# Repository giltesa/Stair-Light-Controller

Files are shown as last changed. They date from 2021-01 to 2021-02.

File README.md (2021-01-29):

# Stair Light - Controller [IN PROGRESS]

This project contain 3 boards for making a LED light controller for using with stairs, corridors, or anything where people can cross, and you want to control light effects automatically.

Boards:

1. Stair Light - Controller
2. Stair Light - Controller MicroSD/USB-C
3. Stair Light - Controller PSU

These boards are made for install them inside a BHT-100GA thermostat. I think It can be difficult to find it now, because I bought it 5 years ago for making a WiFi thermostat but finally I discarded my initially idea.

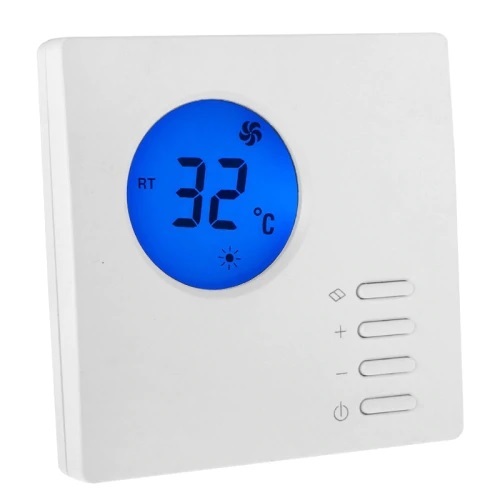
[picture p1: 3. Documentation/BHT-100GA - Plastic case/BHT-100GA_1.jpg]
BHT-100GA


Anyway, you can use the circuit in your own case if you want.

The circuit contains a ESP32 as microcontroller and WiFi/Bluetooth communication, it also has a RS485 controller to connect to the slave sensors to detect people who cross. This is the full list specification:

- **Microcontroller**: ESP32-WROOM / ESP32-WROVER-B (with auto-boot).
- **Communications**: WiFi, Bluetooth, RS485 3V3.
- **Programming port**: USB-C by CP2104.
- **User interface**: IPS round screen, LED status, Switches: Buzzer, Menu, Up, Down, Ok, Reset and Boot.
- **Storage**: MicroSD
- **Others**:
  - Real time clock DS3231 with li-ion battery LIR2032 (or not rechargeable CR2032).
  - Temperature and humidity sensor HTU21D
  - External connector to connect the PSU board (power, NeoPixel and RS485 communication).

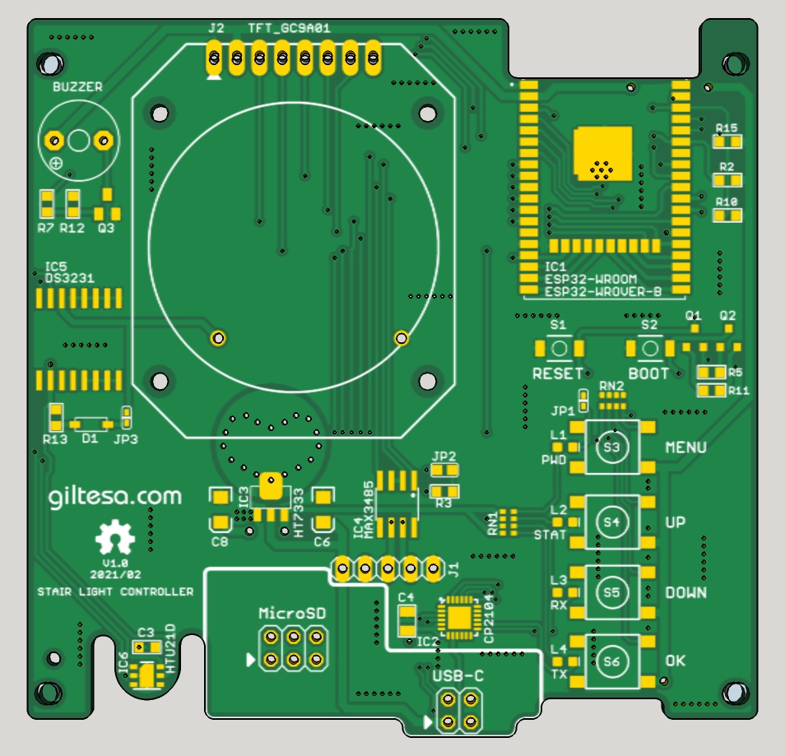
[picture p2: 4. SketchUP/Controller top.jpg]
Stair Light - Controller


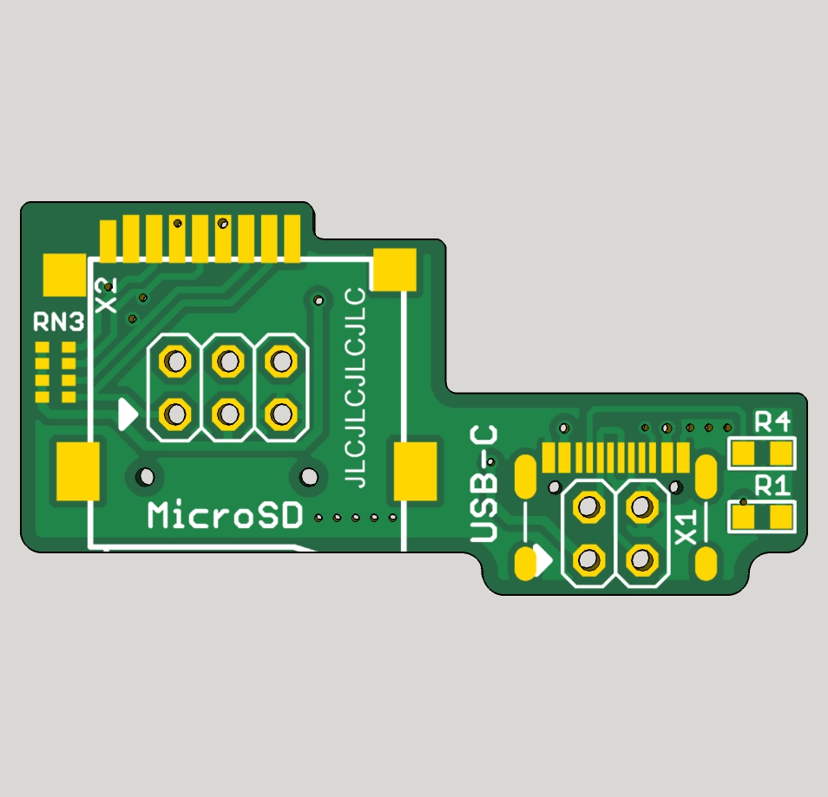
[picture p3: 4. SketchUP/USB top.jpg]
Stair Light - USB


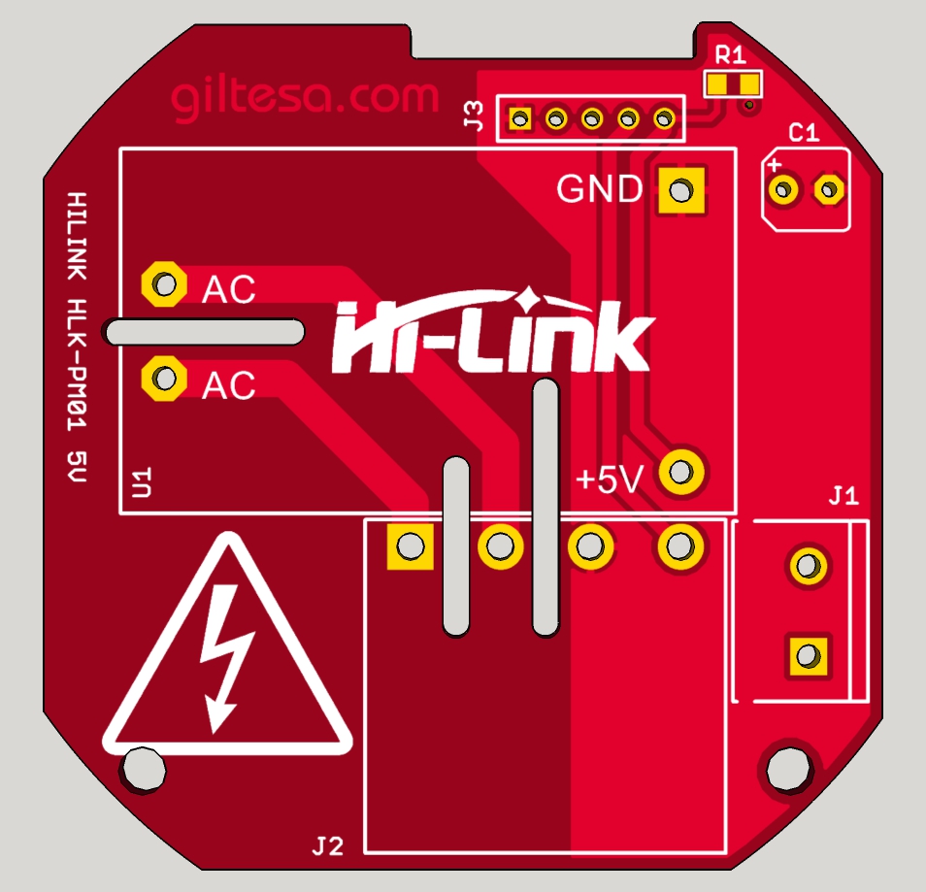
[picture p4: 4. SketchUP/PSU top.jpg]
Stair Light - PSU


## License

This project is licensed under a **Creative Commons** license:
**[Attribution-NonCommercial-ShareAlike 4.0 International (CC BY-NC-SA 4.0) ](https://creativecommons.org/licenses/by-nc-sa/4.0/)**

Check the [LICENSE.md](LICENSE.md) for more information.

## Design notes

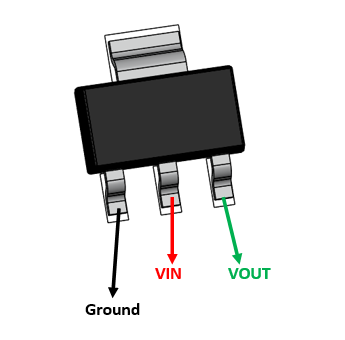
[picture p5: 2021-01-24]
3. Documentation/HT7333 - Linear Voltage Regulator/HT7333-Pinout.PNG

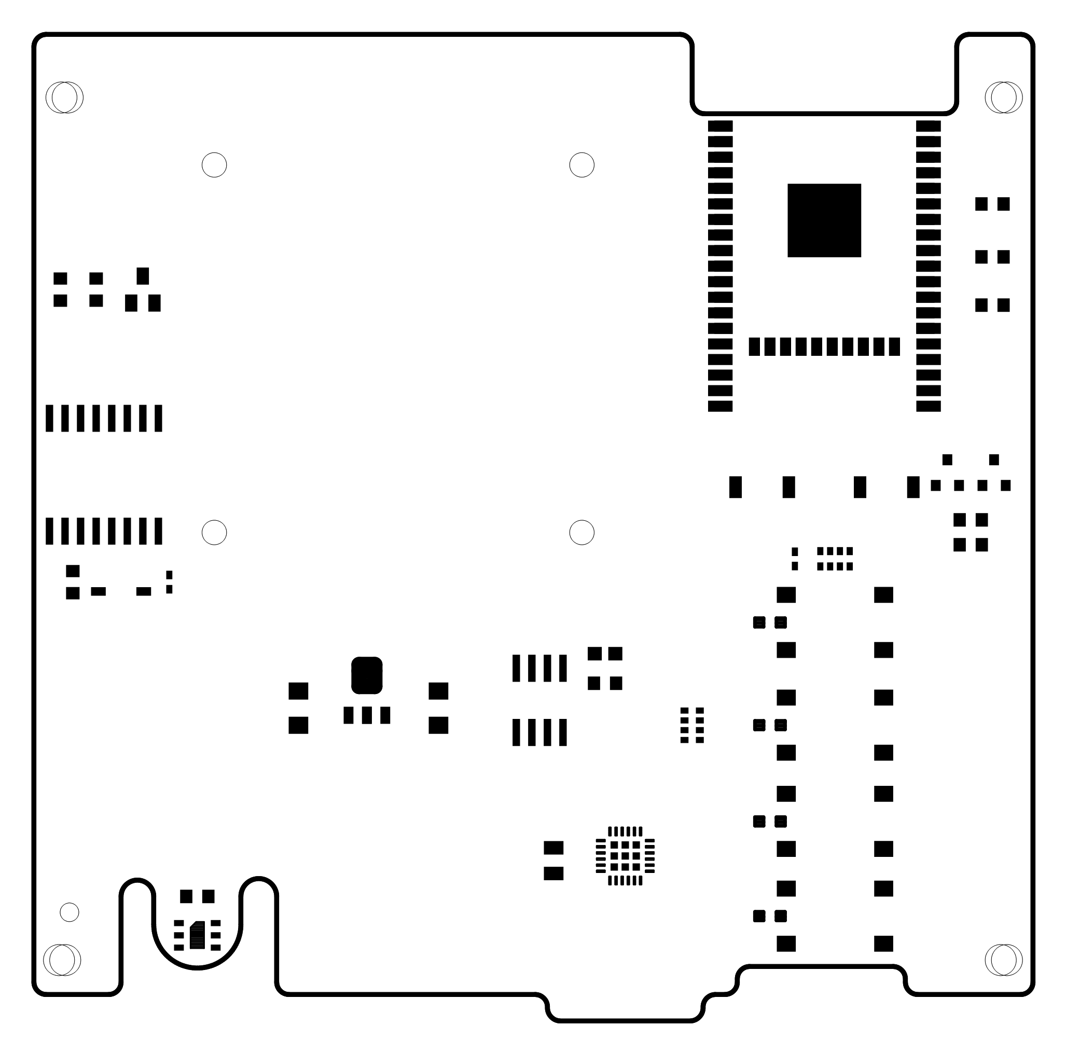
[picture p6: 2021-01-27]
2. Gerbers/1. Stair Light - Controller/v1.0/Images/stair light controller.GTP.png

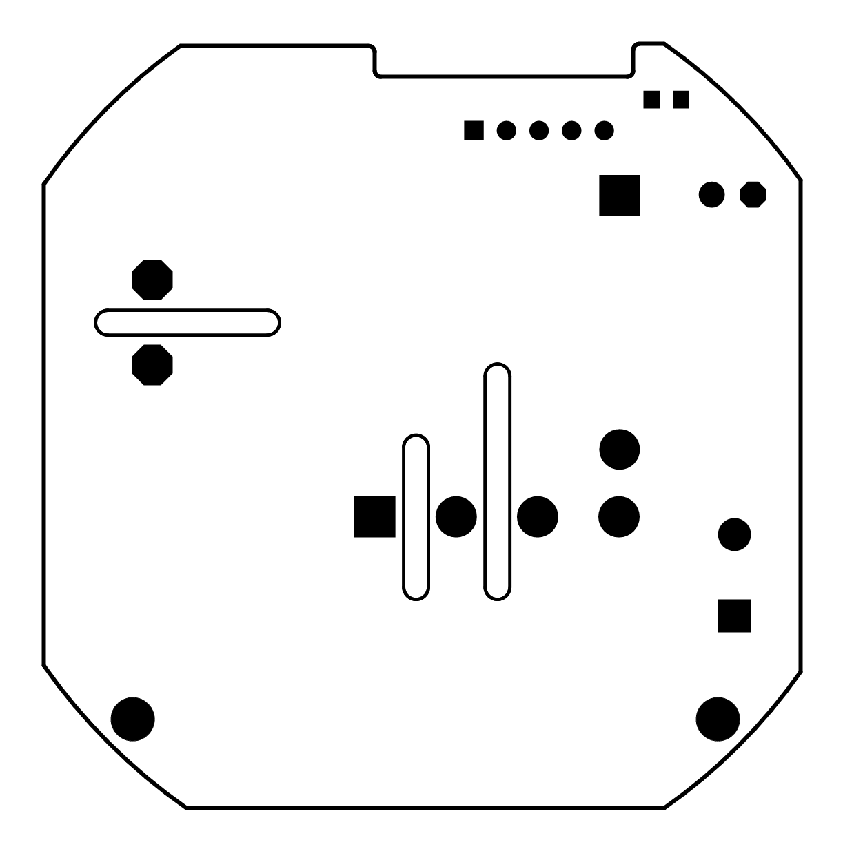
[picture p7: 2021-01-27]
2. Gerbers/3. Stair Light - PSU/v1.0/Images/stair light psu.GTS.png

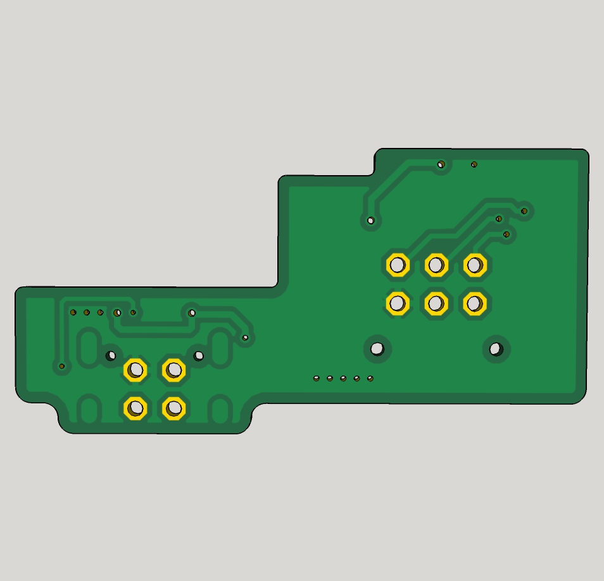
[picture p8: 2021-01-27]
2. Gerbers/2. Stair Light - USB/v1.0/Images/USB bottom.jpg

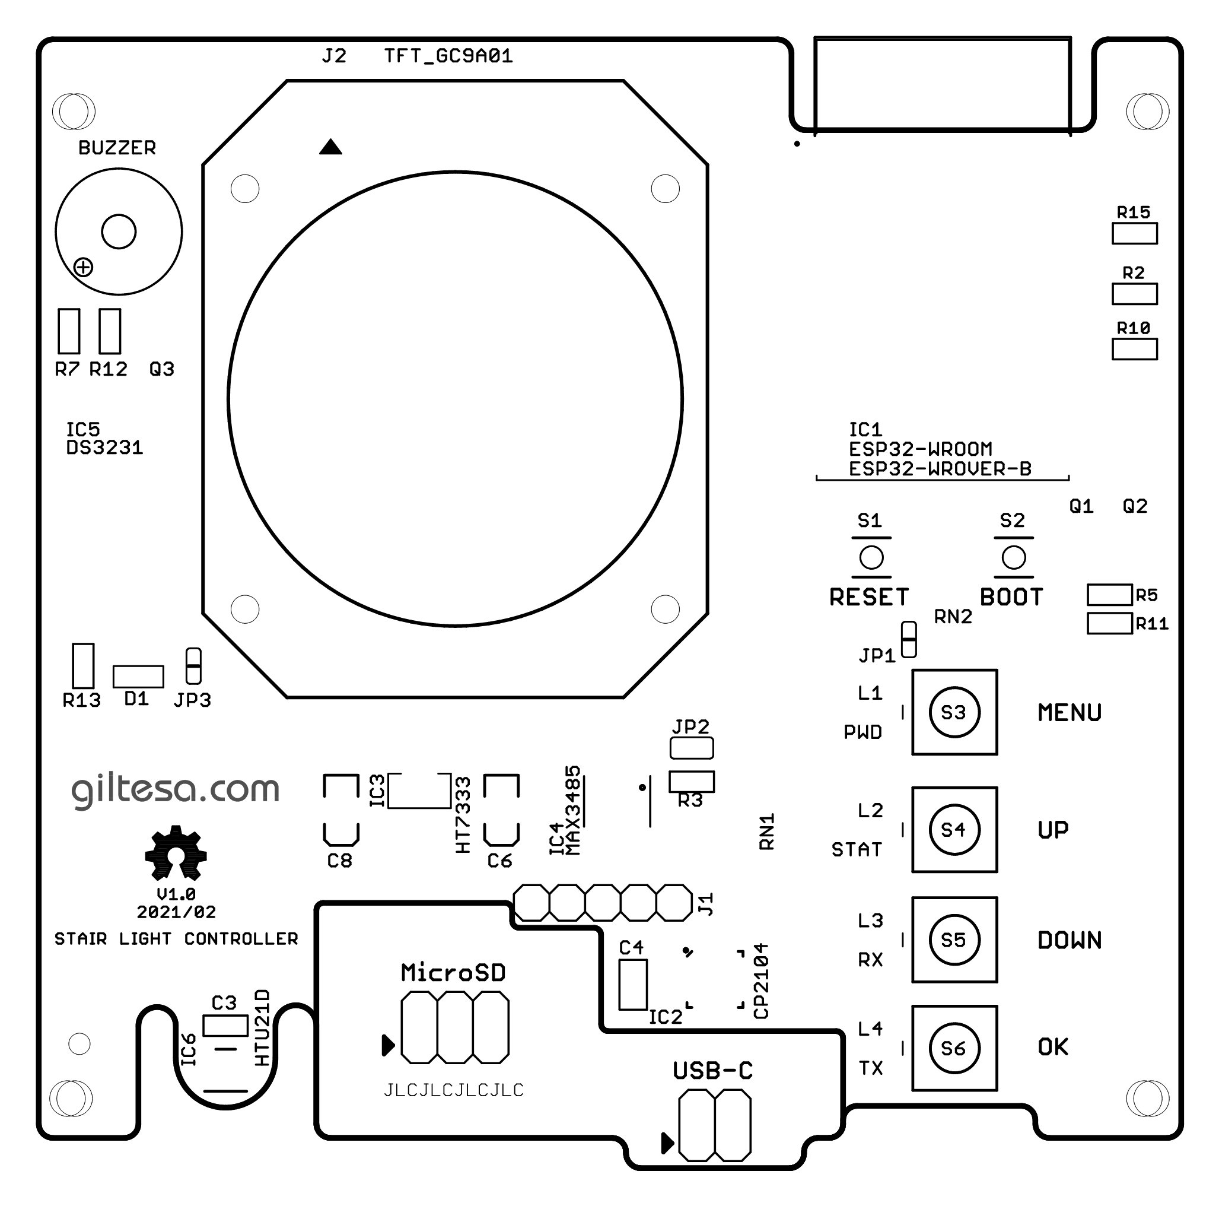
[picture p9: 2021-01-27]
2. Gerbers/1. Stair Light - Controller/v1.0/Images/stair light controller.GTO.png

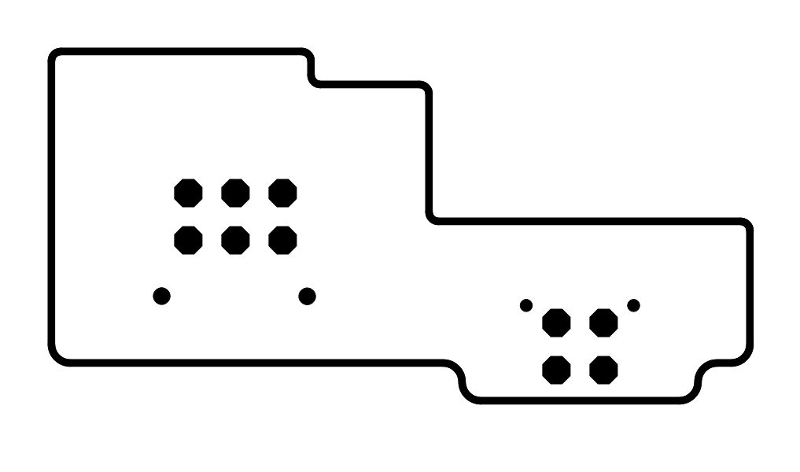
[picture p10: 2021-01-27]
2. Gerbers/2. Stair Light - USB/v1.0/Images/stair light usb.GBS.png

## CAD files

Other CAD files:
4. SketchUP/Controller Sketchup.skp
4. SketchUP/PSU Sketchup.skp
4. SketchUP/USB Sketchup.skp

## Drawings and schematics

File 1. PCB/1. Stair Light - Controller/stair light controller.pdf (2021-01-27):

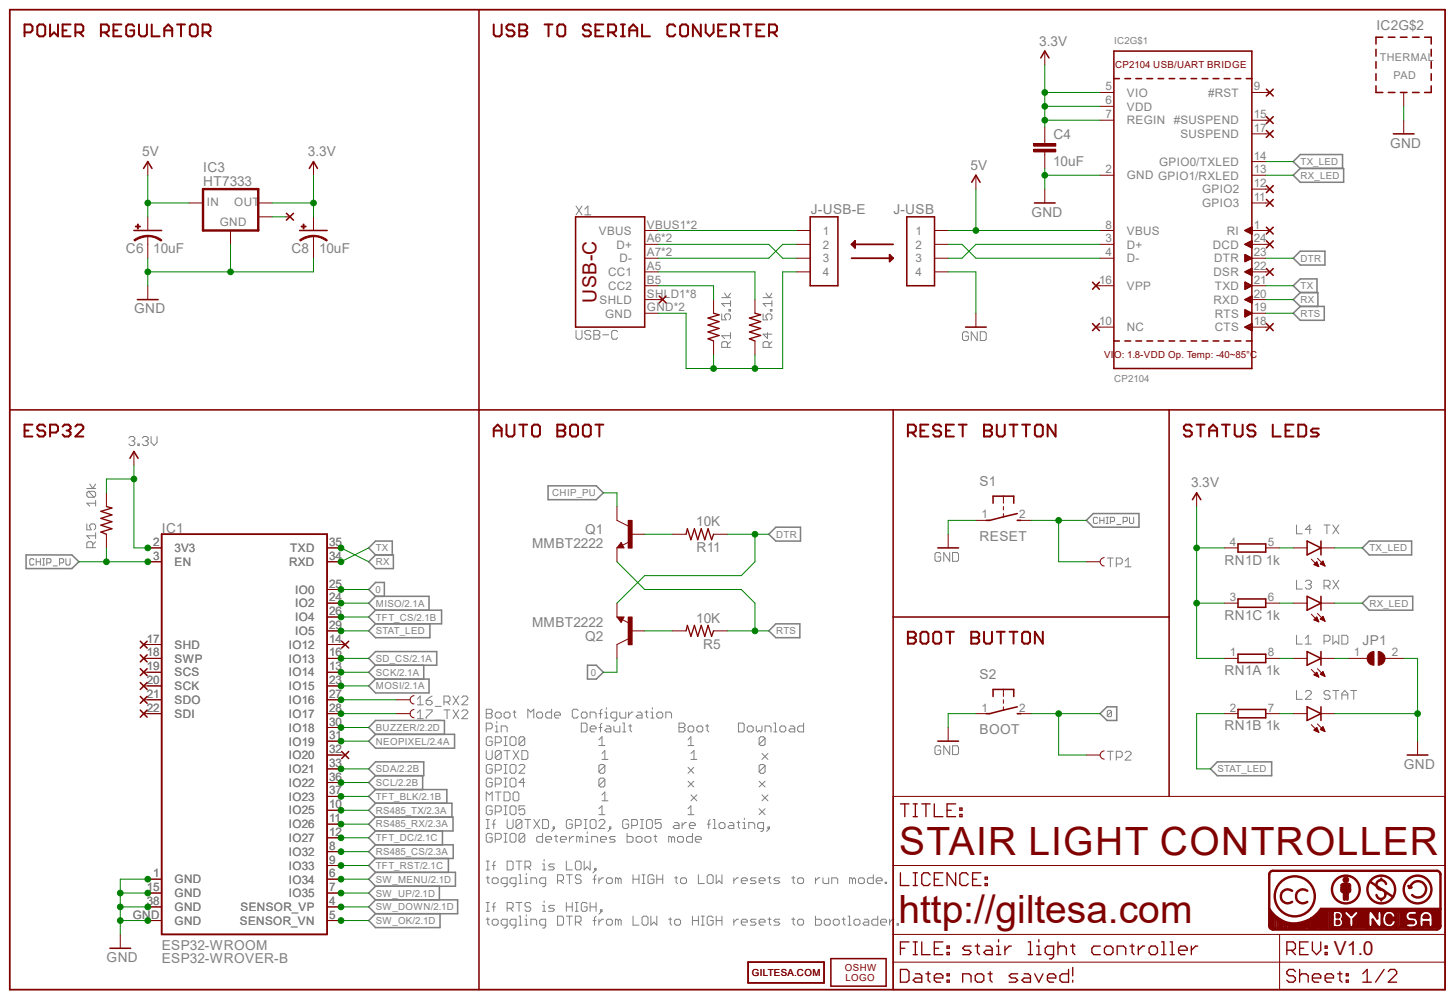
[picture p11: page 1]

VIO: 1.8-VDD Op. Temp: -40~85°C

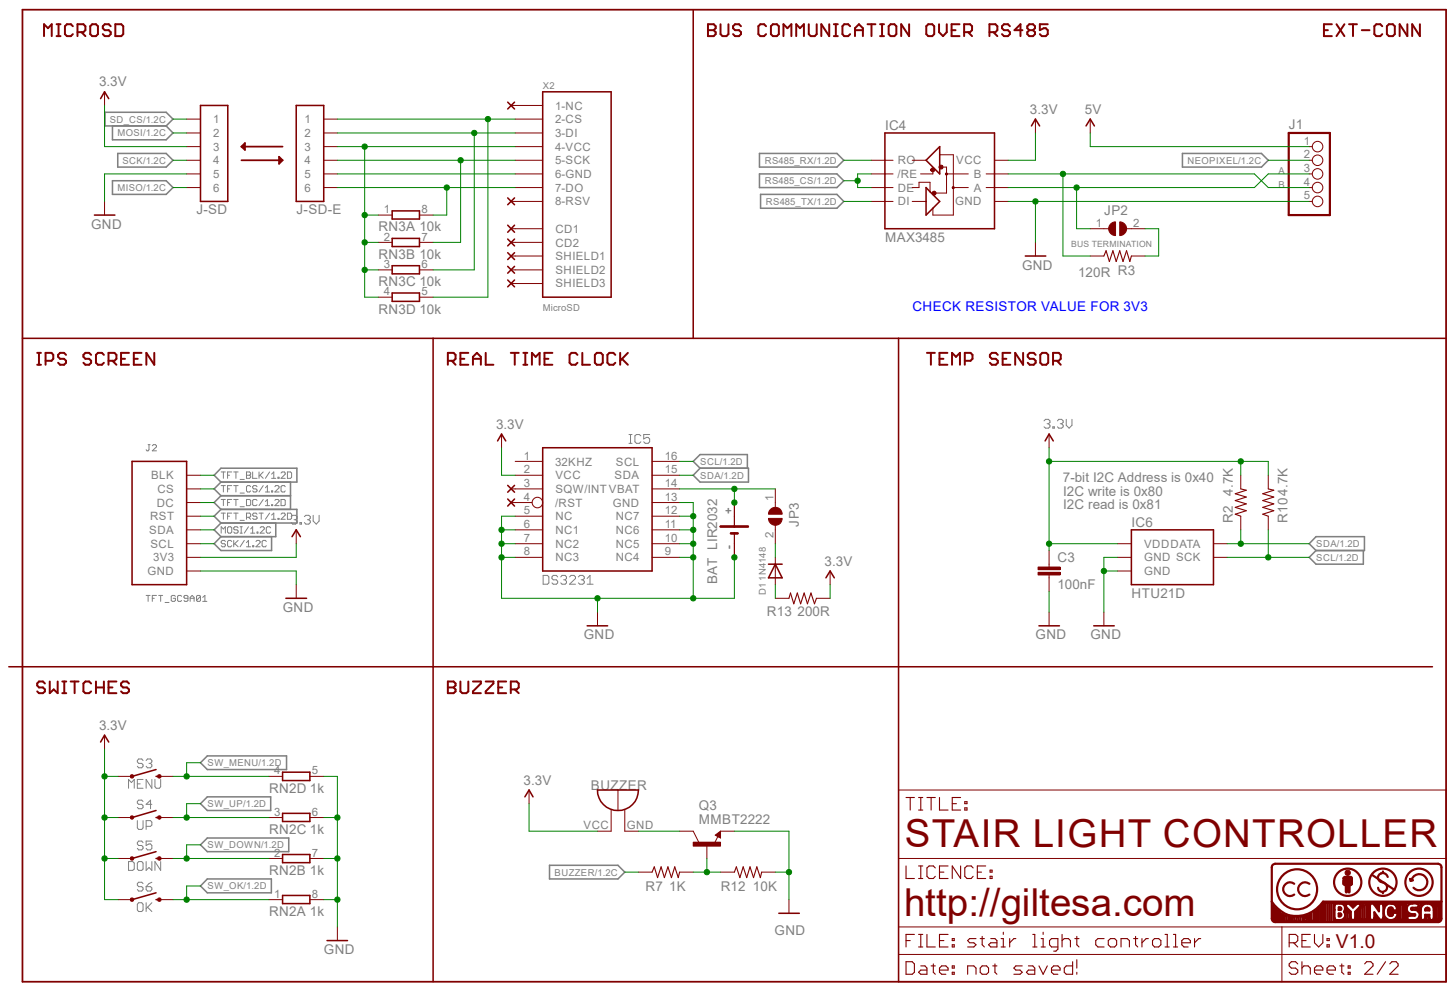
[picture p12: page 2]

CHECK RESISTOR VALUE FOR 3V3

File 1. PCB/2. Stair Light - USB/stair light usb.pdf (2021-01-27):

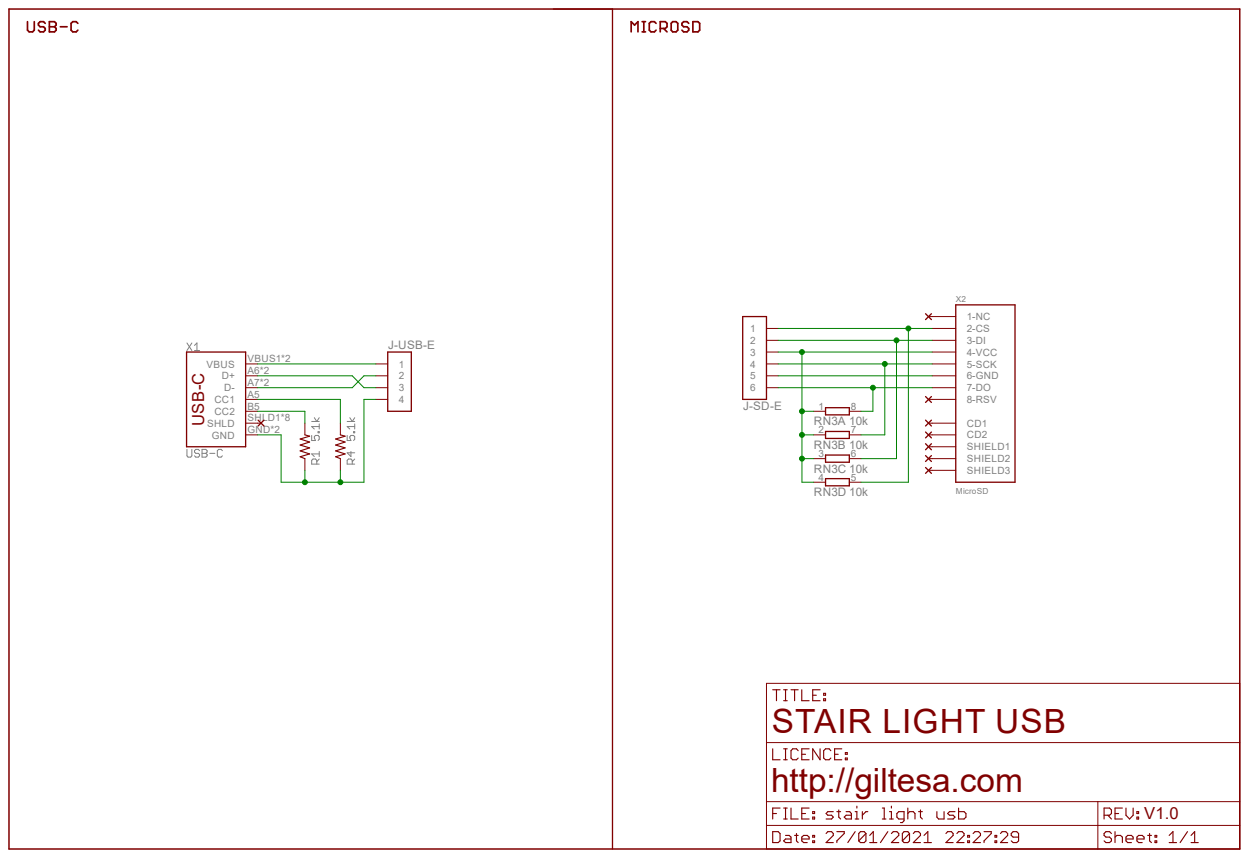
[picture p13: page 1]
MicroSD 10k; 6-GND; 4-VCC 5-SCK; 8-RSV; SHIELD1; SHIELD2 SHIELD3; GND; GND*2; VBUS; VBUS1*2; SHLD; SHLD1*8; J-USB-E; V1.0 USB⁻C

STAIR LIGHT USB
http://giltesa.com

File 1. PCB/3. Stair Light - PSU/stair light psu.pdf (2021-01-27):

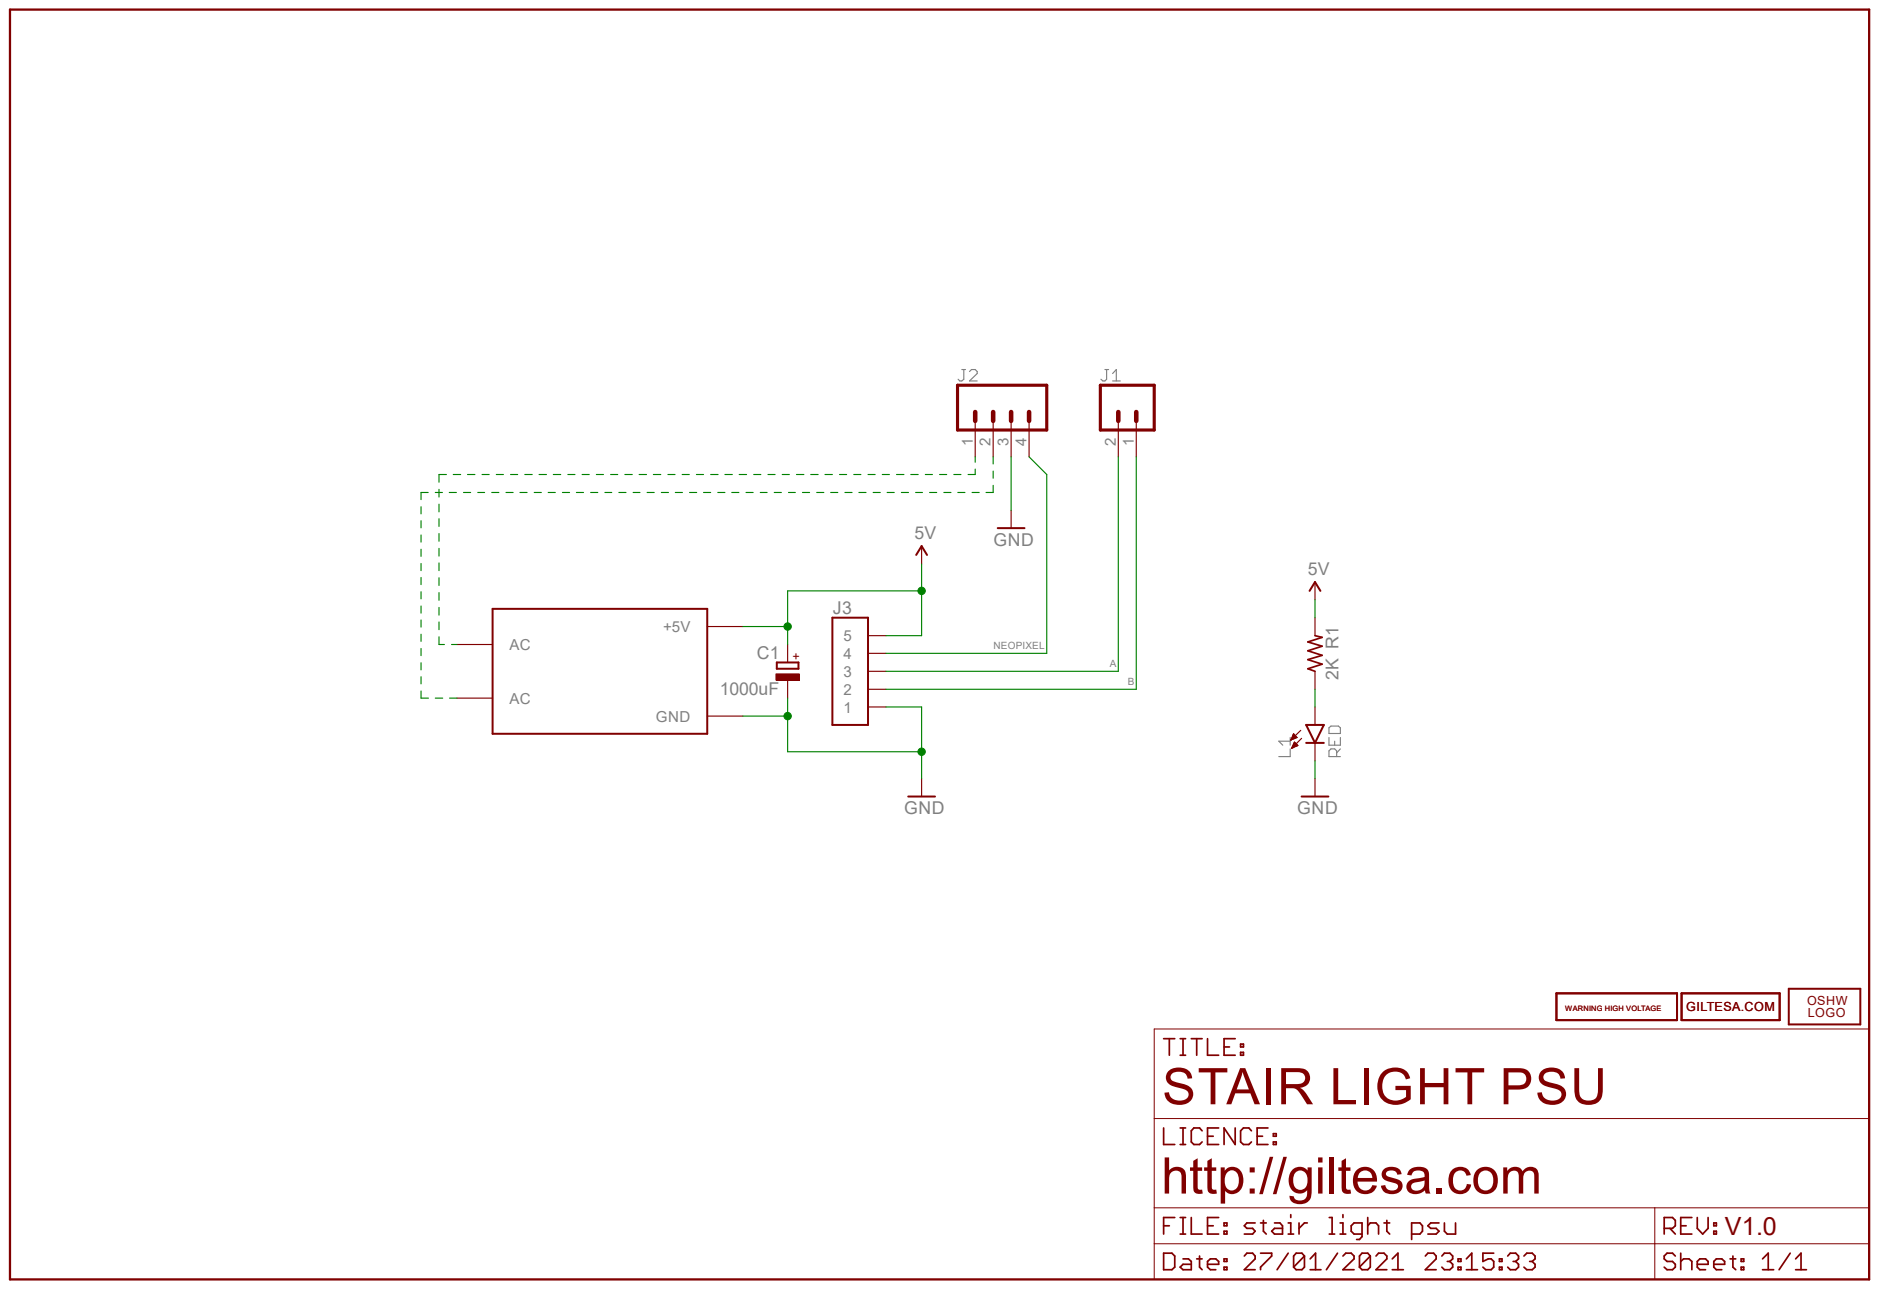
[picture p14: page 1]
GND 5V; GND; GND²K; NEOPIXEL; WARNING HIGH VOLTAGE; GILTESA.COM; OSHW; LOGO

STAIR LIGHT PSU
http://giltesa.com

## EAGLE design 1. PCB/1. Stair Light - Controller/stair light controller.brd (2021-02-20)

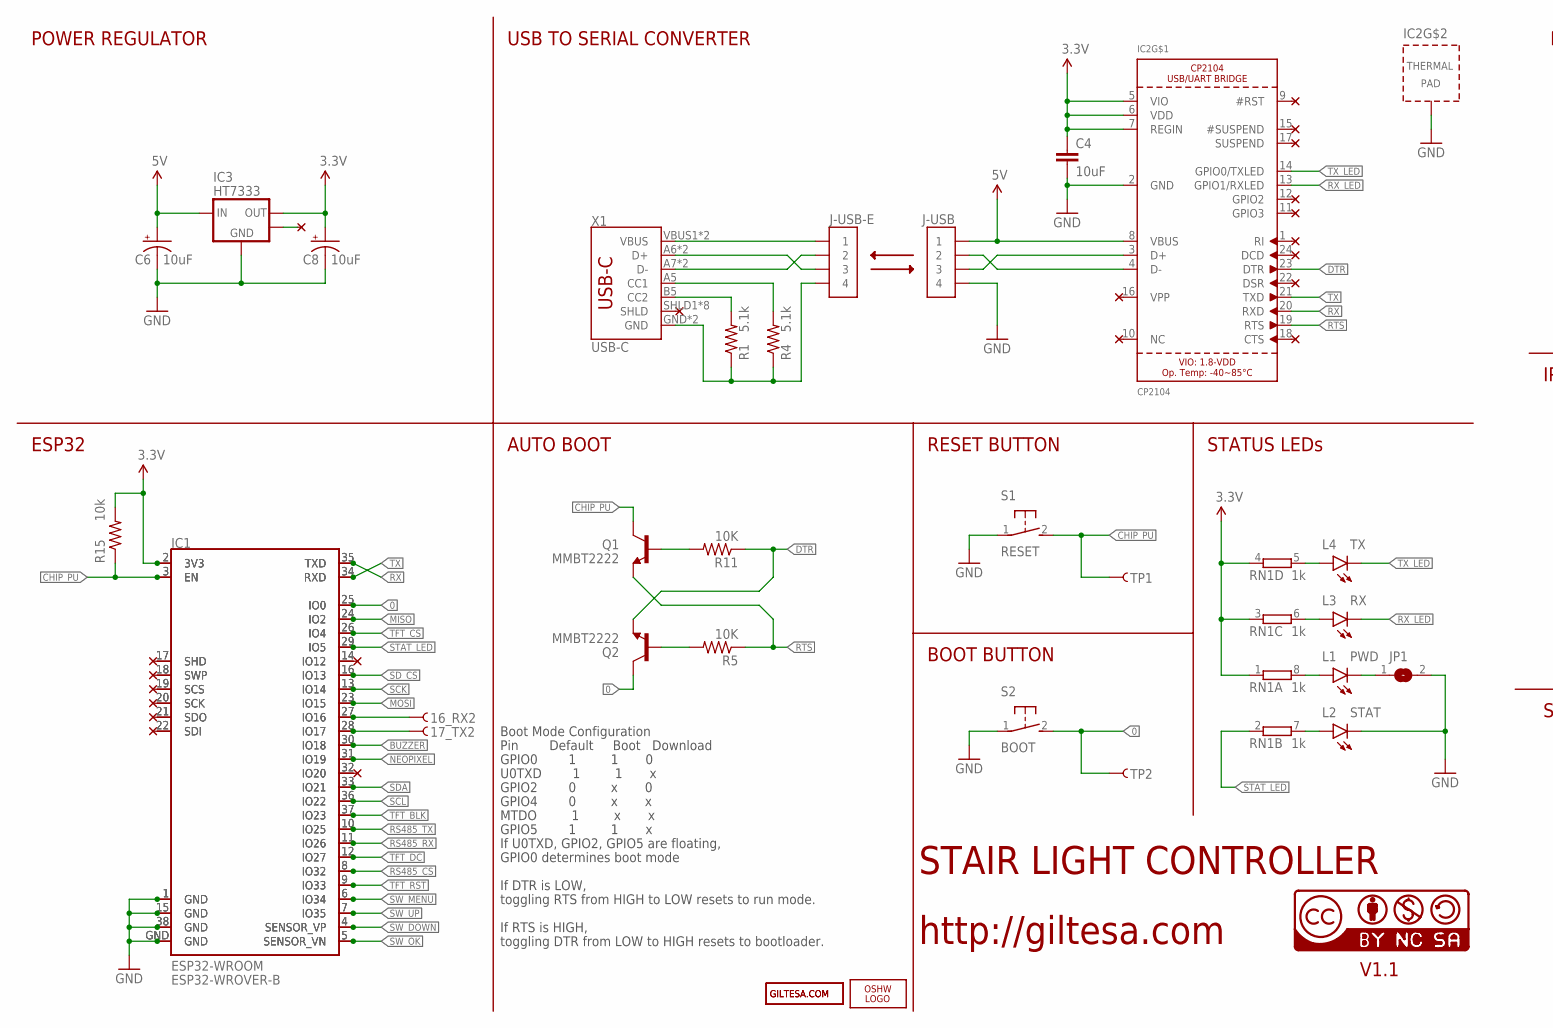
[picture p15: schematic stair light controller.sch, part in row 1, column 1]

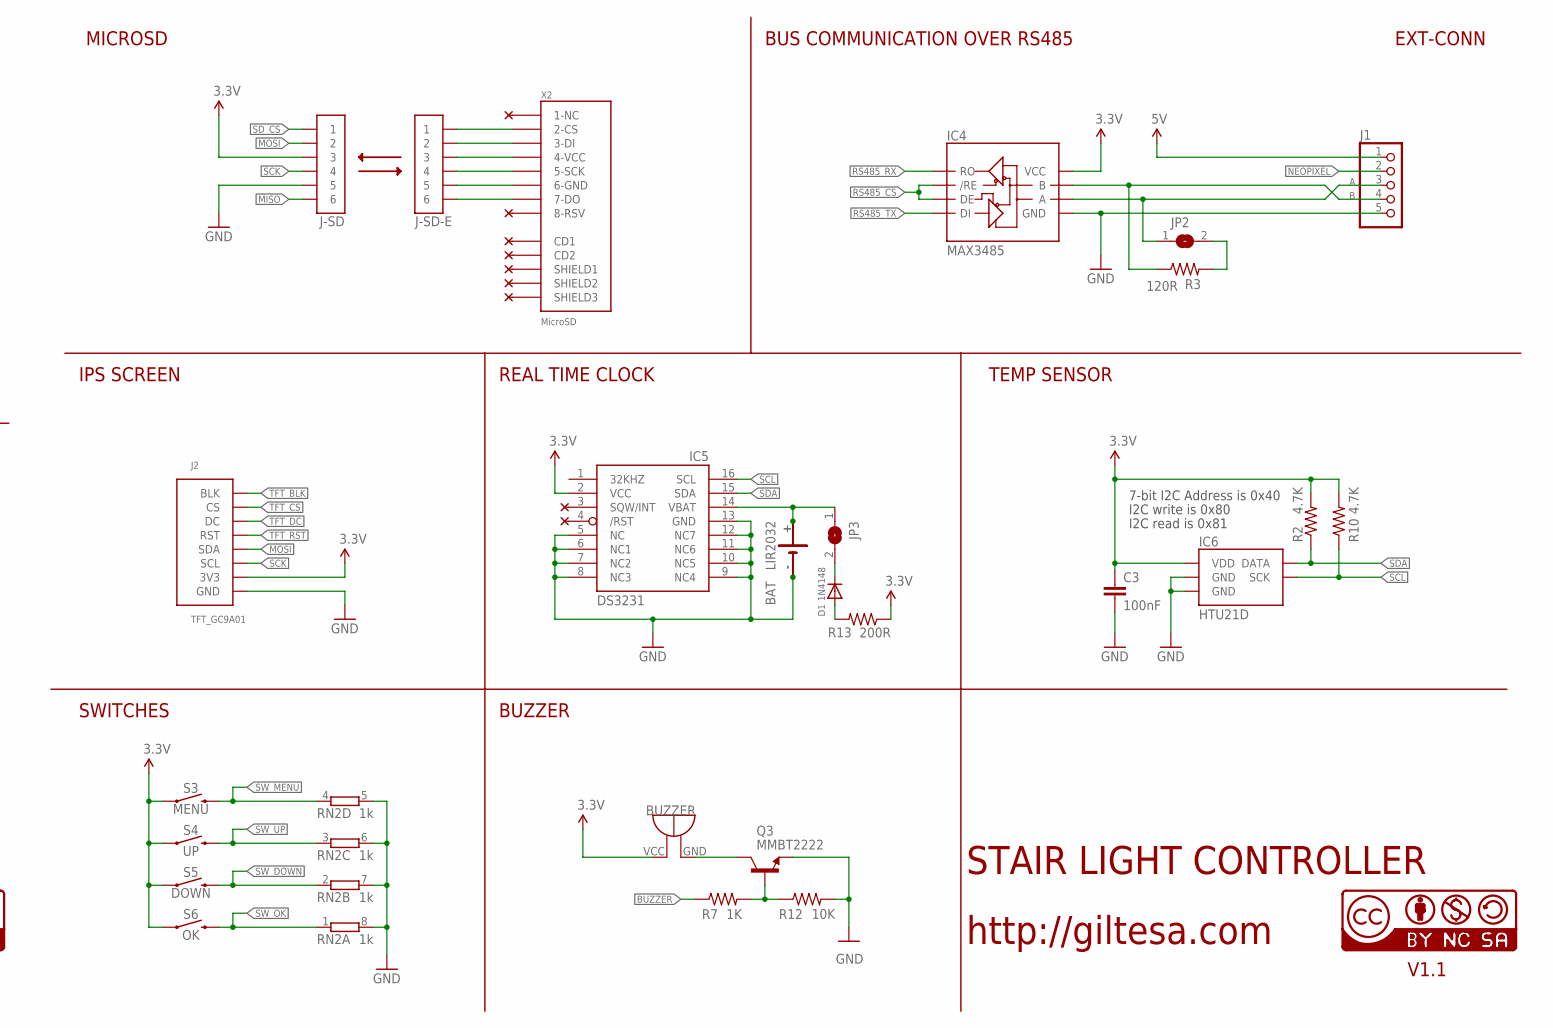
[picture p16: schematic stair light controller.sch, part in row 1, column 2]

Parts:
16_RX2, 17_TX2: TEST-POINTTP_15TH_THRU; TP_15TH
BAT: LIR2032; LIR2032_SMD
BUZZER: BUZZER_9MM
C3: 100nF; C0603
C4: 10uF; C0805
C6, C8: 10uF; EIA3216
D1: 1N4148; SOD-123
IC1: ESP32-WROVER-B
IC2: CP2104; QFN24_4MM_SMSC
IC3: HT7333; SOT89_1
IC4: MAX3485; SO08
IC5: DS3231; SO16W
IC6: HTU21D
J1: PINHD-1X5; 1X05
J2: TFT_GC9A01; LCD_GC9A01
J-SD: 2X03
J-SD-E: 2X03
J-USB: 2X02
J-USB-E: 2X02
JP1, JP3: JUMPER-SMD0402; JUMPER-SMD_0402
JP2: JUMPER-SMD0805; JUMPER-SMD
L1: PWD; LED-0603
L2: STAT; LED-0603
L3: RX; LED-0603
L4: TX; LED-0603
LOGO1: OSHW_LOGO_FILLX0150-NT; OSHW_FILLX150_NOTEXT
Q1, Q2: MMBT2222; SOT23-3
Q3: MMBT2222; SOT23
R1, R4: 5.1k; R0603
R2, R10: 4.7K; R0603
R3: 120R; R0603
R5, R11, R12: 10K; R0603
R7: 1K; R0603
R13: 200R; R0603
R15: 10k; R0603
RN1, RN2: 1k; 0603-ARV
S1: RESET; SWITCH_SMD_4.6X2.8MM
S2: BOOT; SWITCH_SMD_4.6X2.8MM
S3: MENU; TACTILE_SWITCH_SMD_6.2MM_TALL
S4: UP; TACTILE_SWITCH_SMD_6.2MM_TALL
S5: DOWN; TACTILE_SWITCH_SMD_6.2MM_TALL
S6: OK; TACTILE_SWITCH_SMD_6.2MM_TALL
TP1, TP2: TEST-POINTTP_15TH_THRU; TP_15TH
U1": ESP32-WROOM; ESP32-WROOM-NARROW
U$5: CR2032SMT; CR2032
U$9, U$26: CC-NC-BCNIX; CC-NC-B_NIX
U$10: GILTESA.COM_COPPER
U$13: GILTESA.COM_MASK
X1: USB-C; USB-C-16P
X2: MicroSD; MICROSD_2

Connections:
0: IC1.25 (IO0), Q2.3 (C), S2.2 (B), TP2.P$1, U1".25 (IO0)
3.3V: BUZZER.VCC, C3.1, C4.1, C8.A (+), IC1.2 (3V3), IC2.5 (VIO), IC2.6 (VDD), IC2.7 (REGIN), IC3.3 (OUT), IC4.8 (VCC), IC5.2 (VCC), IC6.VDD, J2.3V3, J2.3V3" (3V3), J-SD.3, R2.2, R10.2, R13.1, R15.2, RN1.1, RN1.3 (1), RN1.4 (1), S3.A2 (1), S4.A2 (1), S5.A2 (1), S6.A2 (1), U1".2 (3V3)
5V: C6.A (+), IC2.8 (VBUS), IC3.2 (IN), J1.1, J-USB.1
12: IC1.14 (IO12), U1".14 (IO12)
16_NOT_DEV_PCB_RX2: 16_RX2.P$1, IC1.27 (IO16), U1".27 (IO16)
17_NOT_DEV_PCB_TX2: 17_TX2.P$1, IC1.28 (IO17), U1".28 (IO17)
A: IC4.6 (A), J1.3, JP2.1
B: IC4.7 (B), J1.4, R3.1
BUZZER: IC1.30 (IO18), R7.1, U1".30 (IO18)
CHIP_PU: IC1.3 (EN), Q1.3 (C), R15.1, S1.2 (B), TP1.P$1, U1".3 (EN)
D+: IC2.3 (D+), J-USB.3
D-: IC2.4 (D-), J-USB.2
DTR: IC2.23 (DTR), Q2.2 (E), R11.1
EXT_PCB_3.3V: J-SD-E.3, X2.4-VCC
EXT_PCB_5V: J-USB-E.1, X1.VBUS1 (VBUS), X1.VBUS2 (VBUS)
EXT_PCB_CC1: R4.2, X1.A5 (CC1)
EXT_PCB_CC2: R1.2, X1.B5 (CC2)
EXT_PCB_D+: J-USB-E.3, X1.A6 (D+), X1.B6 (D+)
EXT_PCB_D-: J-USB-E.2, X1.A7 (D-), X1.B7 (D-)
EXT_PCB_GND: J-SD-E.5, J-USB-E.4, R1.1, R4.1, X1.GND, X1.GND2 (GND), X2.6-GND
EXT_PCB_MISO: J-SD-E.6, X2.7-DO
EXT_PCB_MOSI: J-SD-E.2, X2.3-DI
EXT_PCB_SCK: J-SD-E.4, X2.5-SCK
EXT_PCB_SD_CS: J-SD-E.1, X2.2-CS
GND: BAT.-, C3.2, C4.2, C6.C (-), C8.C (-), IC1.1 (GND), IC1.15 (GND), IC1.38 (GND), IC1.GND, IC2.2 (GND), IC2.THERM (TP), IC3.1 (GND), IC4.5 (GND), IC5.5 (NC), IC5.6 (NC1), IC5.7 (NC2), IC5.8 (NC3), IC5.9 (NC4), IC5.10 (NC5), IC5.11 (NC6), IC5.12 (NC7), IC5.13 (GND), IC6.7 (GND), IC6.GND, J1.5, J2.GND, J2.GND" (GND), J-SD.5, J-USB.4, JP1.2, L2.C, Q3.2 (E), R12.2, RN2.5 (2), RN2.6 (2), RN2.7 (2), RN2.8 (2), S1.1 (A), S2.1 (A), U1".1 (GND), U1".15 (GND), U1".38 (GND), U1".GND, U$5.-
MISO: IC1.24 (IO2), J-SD.6, U1".24 (IO2)
MOSI: IC1.23 (IO15), J2.SDA, J2.SDA" (SDA), J-SD.2, U1".23 (IO15)
unnamed: L1.A, RN1.8 (2)
unnamed: L2.A, RN1.7 (2)
unnamed: BAT.+, IC5.14 (VBAT), JP3.1, U$5.+
unnamed: D1.A, R13.2
unnamed: L4.A, RN1.5 (2)
unnamed: L3.A, RN1.6 (2)
unnamed: JP1.1, L1.C
unnamed: JP2.2, R3.2
unnamed: Q3.1 (B), R7.2, R12.1
unnamed: IC1.32 (IO20), U1".32 (IO20)
unnamed: BUZZER.GND, Q3.3 (C)
unnamed: IC1.20 (SCK), U1".20 (SCK)
unnamed: IC1.19 (SCS), U1".19 (SCS)
unnamed: IC1.22 (SDI), U1".22 (SDI)
unnamed: IC1.21 (SDO), U1".21 (SDO)
unnamed: IC1.17 (SHD), U1".17 (SHD)
unnamed: IC1.18 (SWP), U1".18 (SWP)
unnamed: D1.C, JP3.2
unnamed: Q1.1 (B), R11.2
unnamed: Q2.1 (B), R5.2
NEOPIXEL: IC1.31 (IO19), J1.2, U1".31 (IO19)
RS485_CS: IC1.8 (IO32), IC4.2 (/RE), IC4.3 (DE), U1".8 (IO32)
RS485_RX: IC1.11 (IO26), IC4.1 (RO), U1".11 (IO26)
RS485_TX: IC1.10 (IO25), IC4.4 (DI), U1".10 (IO25)
RTS: IC2.19 (RTS), Q1.2 (E), R5.1
RX: IC1.35 (TXD), IC2.20 (RXD), U1".35 (TXD)
RX_LED: IC2.13 (GPIO1/RXLED), L3.C
SCK: IC1.13 (IO14), J2.SCL, J2.SCL" (SCL), J-SD.4, U1".13 (IO14)
SCL: IC1.36 (IO22), IC5.16 (SCL), IC6.SCK, R10.1, U1".36 (IO22)
SDA: IC1.33 (IO21), IC5.15 (SDA), IC6.DATA, R2.1, U1".33 (IO21)
SD_CS: IC1.16 (IO13), J-SD.1, U1".16 (IO13)
STAT_LED: IC1.29 (IO5), RN1.2 (1), U1".29 (IO5)
SW_DOWN: IC1.4 (SENSOR_VP), RN2.2 (1), S5.B2 (2), U1".4 (SENSOR_VP)
SW_MENU: IC1.6 (IO34), RN2.4 (1), S3.B2 (2), U1".6 (IO34)
SW_OK: IC1.5 (SENSOR_VN), RN2.1, S6.B2 (2), U1".5 (SENSOR_VN)
SW_UP: IC1.7 (IO35), RN2.3 (1), S4.B2 (2), U1".7 (IO35)
TFT_BLK: IC1.37 (IO23), J2.BLK, J2.BLK" (BLK), U1".37 (IO23)
TFT_CS: IC1.26 (IO4), J2.CS, J2.CS" (CS), U1".26 (IO4)
TFT_DC: IC1.12 (IO27), J2.DC, J2.DC" (DC), U1".12 (IO27)
TFT_RST: IC1.9 (IO33), J2.RST, J2.RST" (RST), U1".9 (IO33)
TX: IC1.34 (RXD), IC2.21 (TXD), U1".34 (RXD)
TX_LED: IC2.14 (GPIO0/TXLED), L4.C

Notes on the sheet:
STAIR LIGHT CONTROLLER
http://giltesa.com
V1.1
POWER REGULATOR
USB TO SERIAL CONVERTER
REAL TIME CLOCK
If DTR is LOW,
If RTS is HIGH,
Boot Mode Configuration
Pin Default Boot Download
GPIO0 1 1 0
U0TXD 1 1 x
GPIO2 0 x 0
GPIO4 0 x x
MTDO 1 x x
GPIO5 1 1 x
If U0TXD, GPIO2, GPIO5 are floating,
GPIO0 determines boot mode
RESET BUTTON
STATUS LEDs
BOOT BUTTON
7-bit I2C Address is 0x40
I2C write is 0x80
I2C read is 0x81
TEMP SENSOR
SWITCHES
ESP32
AUTO BOOT
toggling RTS from HIGH to LOW resets to run mode.
toggling DTR from LOW to HIGH resets to bootloader.
MICROSD
EXT-CONN
IPS SCREEN
BUS COMMUNICATION OVER RS485
BUZZER

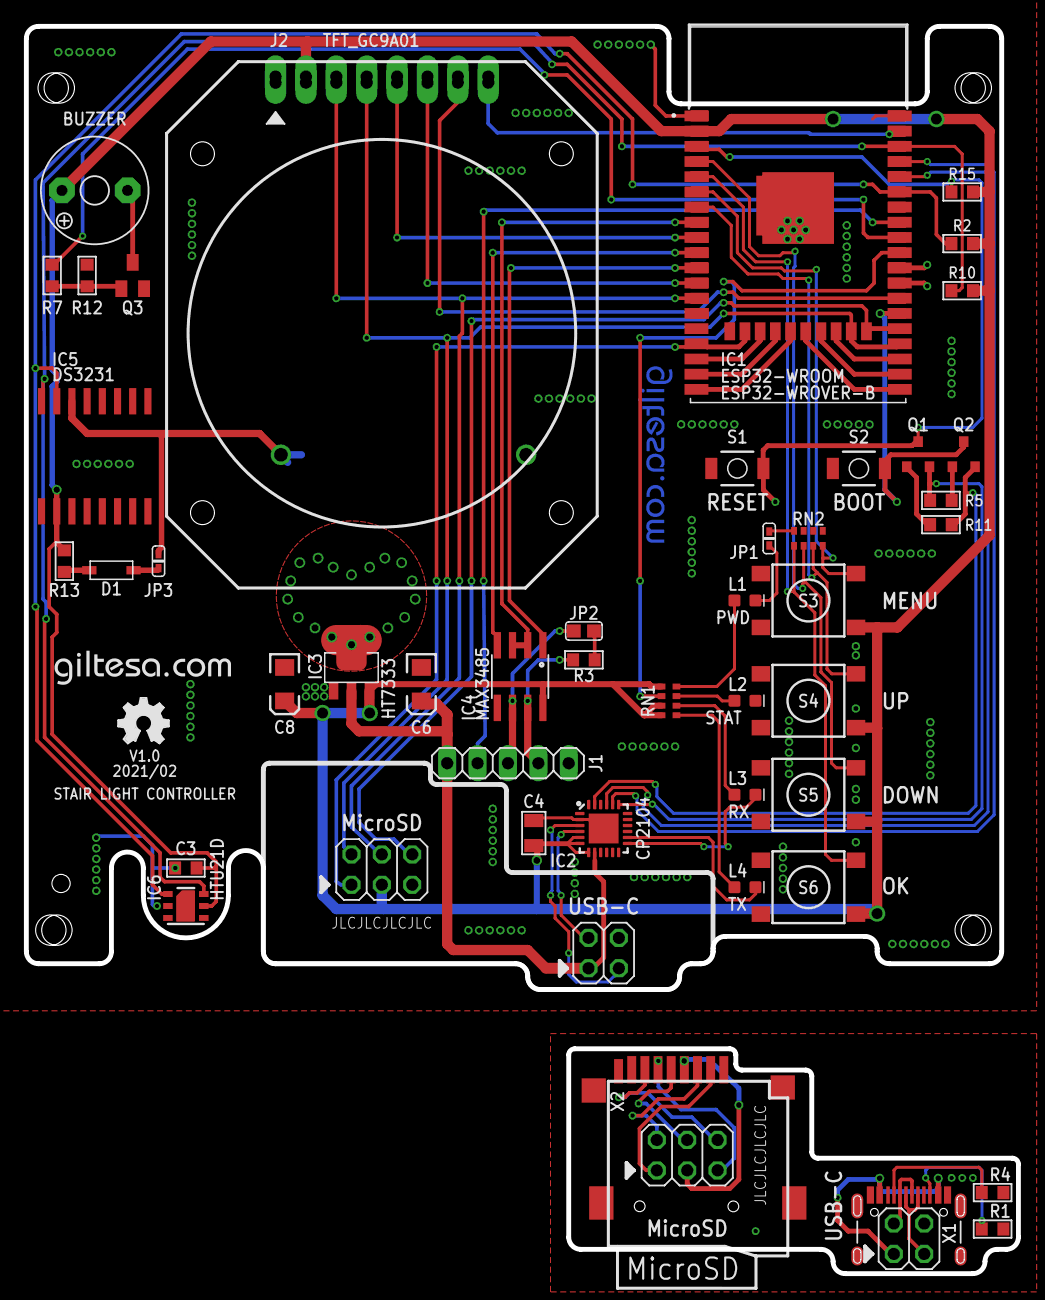
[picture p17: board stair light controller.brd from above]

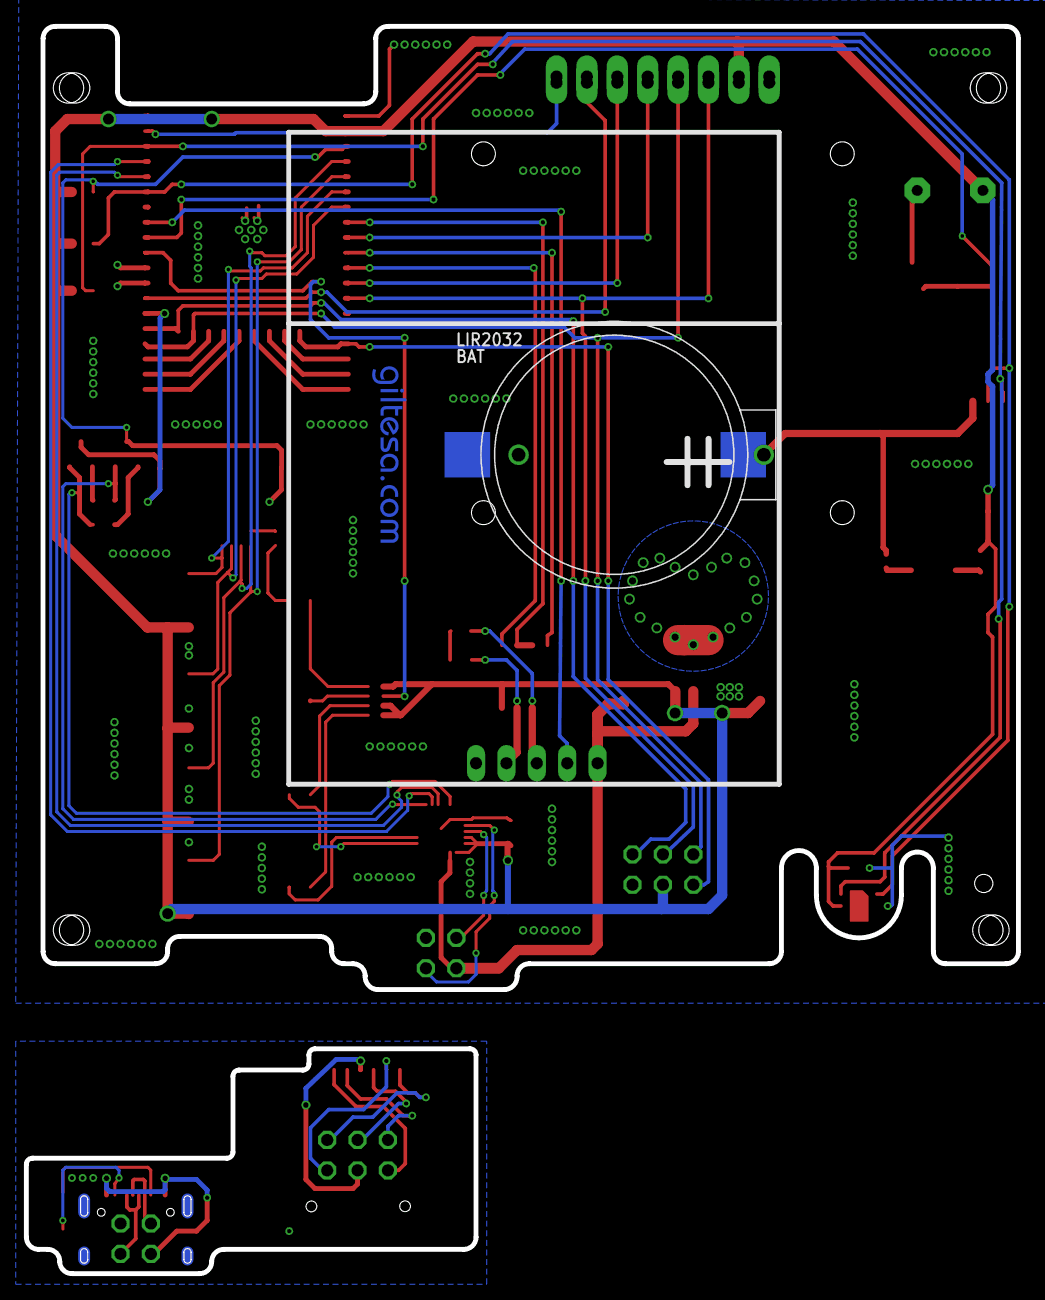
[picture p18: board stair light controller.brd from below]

Board: 2 copper layers, 81.5 x 80.5 mm, 61 parts (3 on the bottom side), 69 nets.

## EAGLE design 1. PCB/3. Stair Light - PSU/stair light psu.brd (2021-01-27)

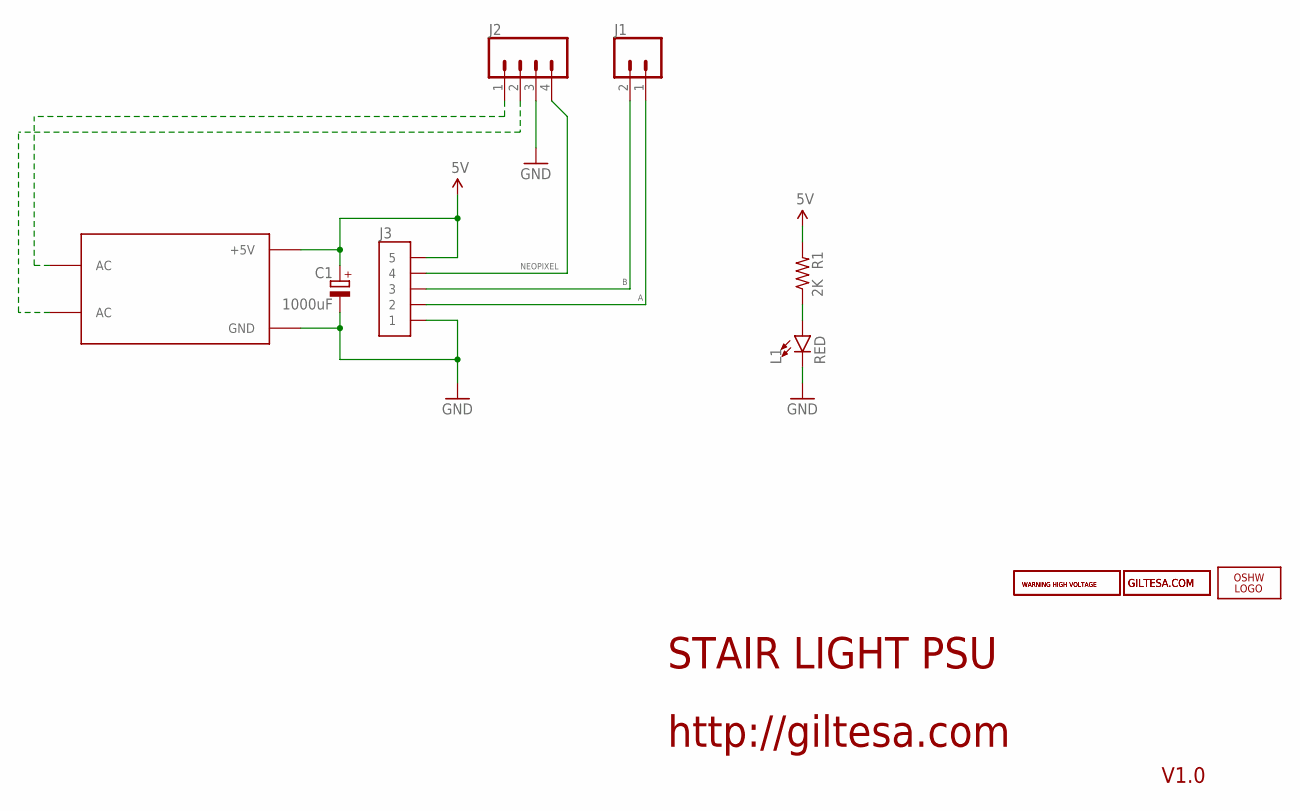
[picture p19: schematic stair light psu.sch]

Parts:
C1: 1000uF; B45181A
J1: TERMINAL_5MM_2P1; TERMINAL_5MM_2P
J2: TERMINAL_5MM_4P_90º_20A
J3: 1X05; 1X5_SMT_2MM
L1: RED; LED-0603
LOGO1: OSHW_LOGO_FILLX0150-NT; OSHW_FILLX150_NOTEXT
R1: 2K; R0603
U1: HILINK HLK-PM01 5V; HILINK_HLK-PM01_5V
U$3, U$6: WARNING_HIGH_VOLTAGE1; WARNING_HIGH_VOLTAGE
U$10: GILTESA.COM_COPPER
U$13: GILTESA.COM_MASK

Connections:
5V: C1.+, J3.5, R1.2, U1.+5V
A: J1.1, J3.2
B: J1.2, J3.3
GND: C1.-, J2.3, J3.1, L1.C, U1.GND
unnamed: L1.A, R1.1
unnamed: J2.1, U1.AC@2 (AC)
unnamed: J2.2, U1.AC@1 (AC)
NEOPIXEL: J2.4, J3.4

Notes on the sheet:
STAIR LIGHT PSU
http://giltesa.com
V1.0

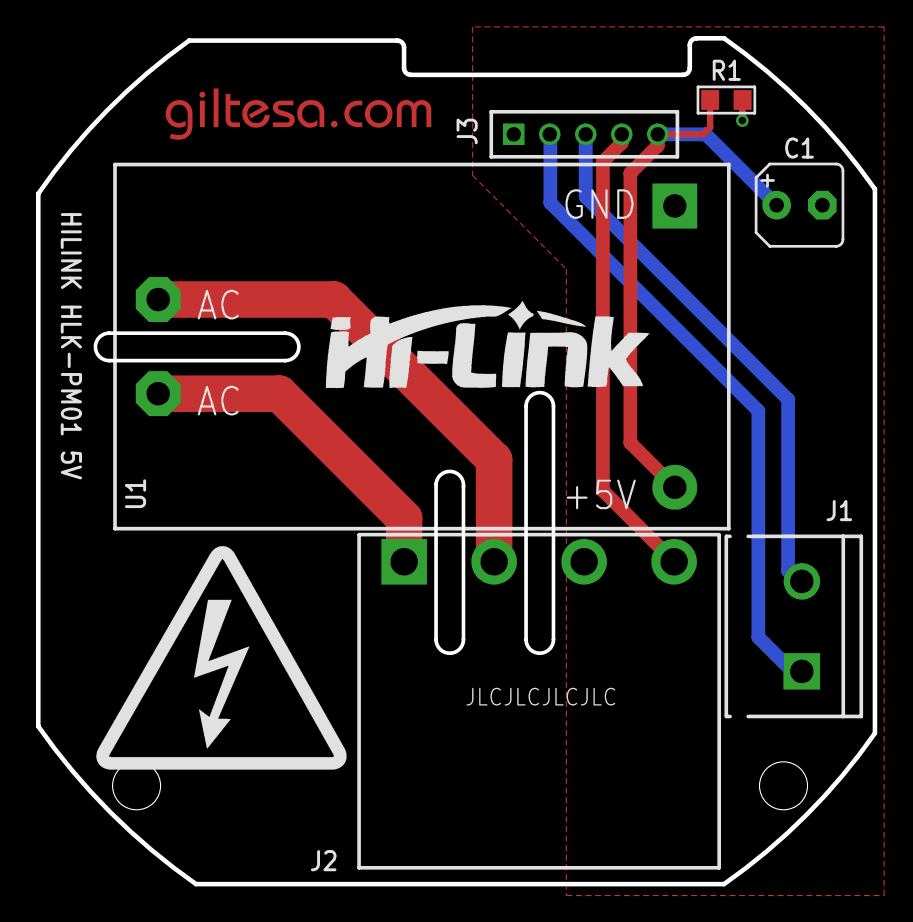
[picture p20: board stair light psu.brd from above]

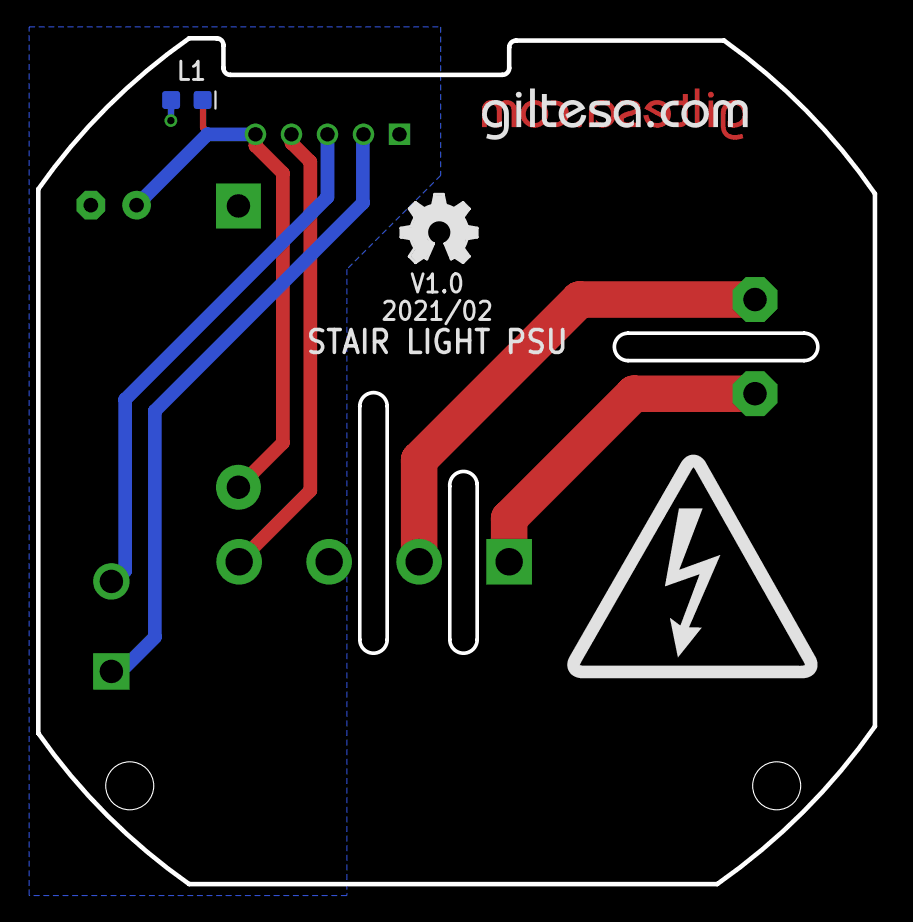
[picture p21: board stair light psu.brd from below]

Board: 2 copper layers, 46.5 x 47.0 mm, 12 parts (4 on the bottom side), 8 nets.

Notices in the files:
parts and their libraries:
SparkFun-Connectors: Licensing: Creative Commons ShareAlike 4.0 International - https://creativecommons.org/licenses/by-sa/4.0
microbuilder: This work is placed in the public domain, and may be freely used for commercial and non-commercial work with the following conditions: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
